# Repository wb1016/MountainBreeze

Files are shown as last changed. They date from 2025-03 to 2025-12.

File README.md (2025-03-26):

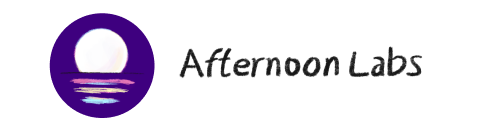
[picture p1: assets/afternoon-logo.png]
Afternoon Labs Logo


# Mountain Breeze

> Ergonomics meets Productivity.

## Introduction

"Mountain Breeze" is a tented split mechanical keyboard with a column-staggered layout. With a focus on productivity, Breeze features a full 6x4 alphanumeric layout, arrow keys, and an extra 6 key cluster for typing and coding.

Learn more at: [www.afternoonlabs.com/mountain-breeze](https://www.afternoonlabs.com/mountain-breeze)

## Features

* Tented Split Ergonomics
* Productivity Cluster for Typing and Coding
* Wireless-First, Fits a Giant Battery
* Built-in On/Off Switch
* Open-source PCB design for easy modifications
* Hotswap MX or Choc Sockets, MX Sockets Built-in!
* Diodes Built-in, No Diode Soldering Required
* Columnar Stagger
* Arrow Keys!

## Support us

Enjoying the Breeze? [Buy me a beer](https://www.buymeacoffee.com/Afternoonlabs).

## Contribution

Contributions are encouraged! Whether it's bug fixes, new features, or even simple feedback, everything helps in making the project better.

1. Fork the Project
2. Create your Feature Branch (`git checkout -b feature/SomeFeature`)
3. Commit your Changes (`git commit -m 'Adding SomeFeature'`)
4. Push to the Branch (`git push origin feature/SomeFeature`)
5. Open a Pull Request

## License

Anyone can use this project for personal use. Distributed under the MIT License. See `LICENSE` for more information.

Vendors interested in selling the Breeze, please contact us below.

The use of "Afternoon Labs" is protected under copyright law. Unauthorized use without express permission from "Afternoon Labs", is prohibited.

## Contact

Join our [Discord Server](https://discord.gg/9nsApe3GvG).

Afternoon Labs - [hi@afternoonlabs.com](mailto:hi@afternoonlabs.com)

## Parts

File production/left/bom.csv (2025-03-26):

Designator | Footprint | Quantity | Value | LCSC Part #
BATT_CONN1 | BATT_PADS | 1 | ~
D1, D10, D11, D12, D13, D14, D15, D16, D17, D18, D19, D2, D20, D21, D22, D23, D24, D3, D4, D5, D6, D7, D8, D9, DTC1, DTC2, DTC3, DTC4 | SOD-123FL | 28 | DIODE | C64898
H18, H19, H2, H3, H4, H5, H6, H7, H8, H9 | M3-HOLE | 10 | M3-HOLE
LGO1 | logo | 1 | Logo
MCU-MAIN1 | ProMicro_1-Sided | 1 | PRO-MICRO
PWR1 | SS12D00 | 1 | SW_SPDT | C145861
RST1 | SW_SPST_TL3342 | 1 | SW-RST | C2886897
STABL1 | Stabilizer_MX_2u | 1 | MX-STABILIZER-2U
SW1, SW10, SW11, SW12, SW13, SW14, SW15, SW16, SW17, SW18, SW19, SW2, SW20, SW21, SW22, SW23, SW24, SW3, SW4, SW5, SW6, SW7, SW8, SW9, TC1, TC2, TC3, TC4 | MX_Choc_Hotswap_1-Sided | 28 | CHOCXHSPCB-1U | C41430893

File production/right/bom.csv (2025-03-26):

Designator | Footprint | Quantity | Value | LCSC Part #
D1, D10, D11, D12, D13, D14, D15, D16, D17, D18, D19, D2, D20, D21, D22, D23, D24, D3, D4, D5, D6, D7, D8, D9, DALF1, DAN1, DMC1, DMC2, DMC3, DMC4, DMC5, DMC6, DRT1, DTC1, DTC2, DTC3, DTC4, DUP1 | SOD-123FL | 38 | DIODE | C64898
DOWN1, LEFT1, MC1, MC2, MC3, MC4, MC5, MC6, RIGHT1, SW1, SW10, SW11, SW12, SW13, SW14, SW15, SW16, SW17, SW18, SW19, SW2, SW20, SW21, SW22, SW23, SW24, SW3, SW4, SW5, SW6, SW7, SW8, SW9, TC1, TC2, TC3, TC4, UP1 | MX_Choc_Hotswap_1-Sided | 38 | CHOCXHSPCB-1U | C41430893
H1, H10, H16, H17, H18, H19, H2, H3, H4, H5, H6, H7, H8, H9 | M3-HOLE | 14 | M3-HOLE
H11, H13, H15 | M2-HOLE | 3 | 2M-HOLE
J1 | BATT_PADS | 1 | J
J_FUNCT1, J_RIGHT1 | PinHeader_1x03_P2.54mm_Vertical | 2 | Conn_01x04
J_FUNCT2, J_RIGHT2 | PinHeader_1x04_P2.54mm_Vertical | 2 | Conn_01x04
LGO1 | logo | 1 | Logo
MCU-MAIN1 | ProMicro_1-Sided | 1 | PRO-MICRO
PWR1 | SS12D00 | 1 | SW_SPDT | C145861
RST1 | SW_SPST_TL3342 | 1 | SW-RST | C2886897
STABL1 | Stabilizer_MX_2u | 1 | MX-STABILIZER-2U

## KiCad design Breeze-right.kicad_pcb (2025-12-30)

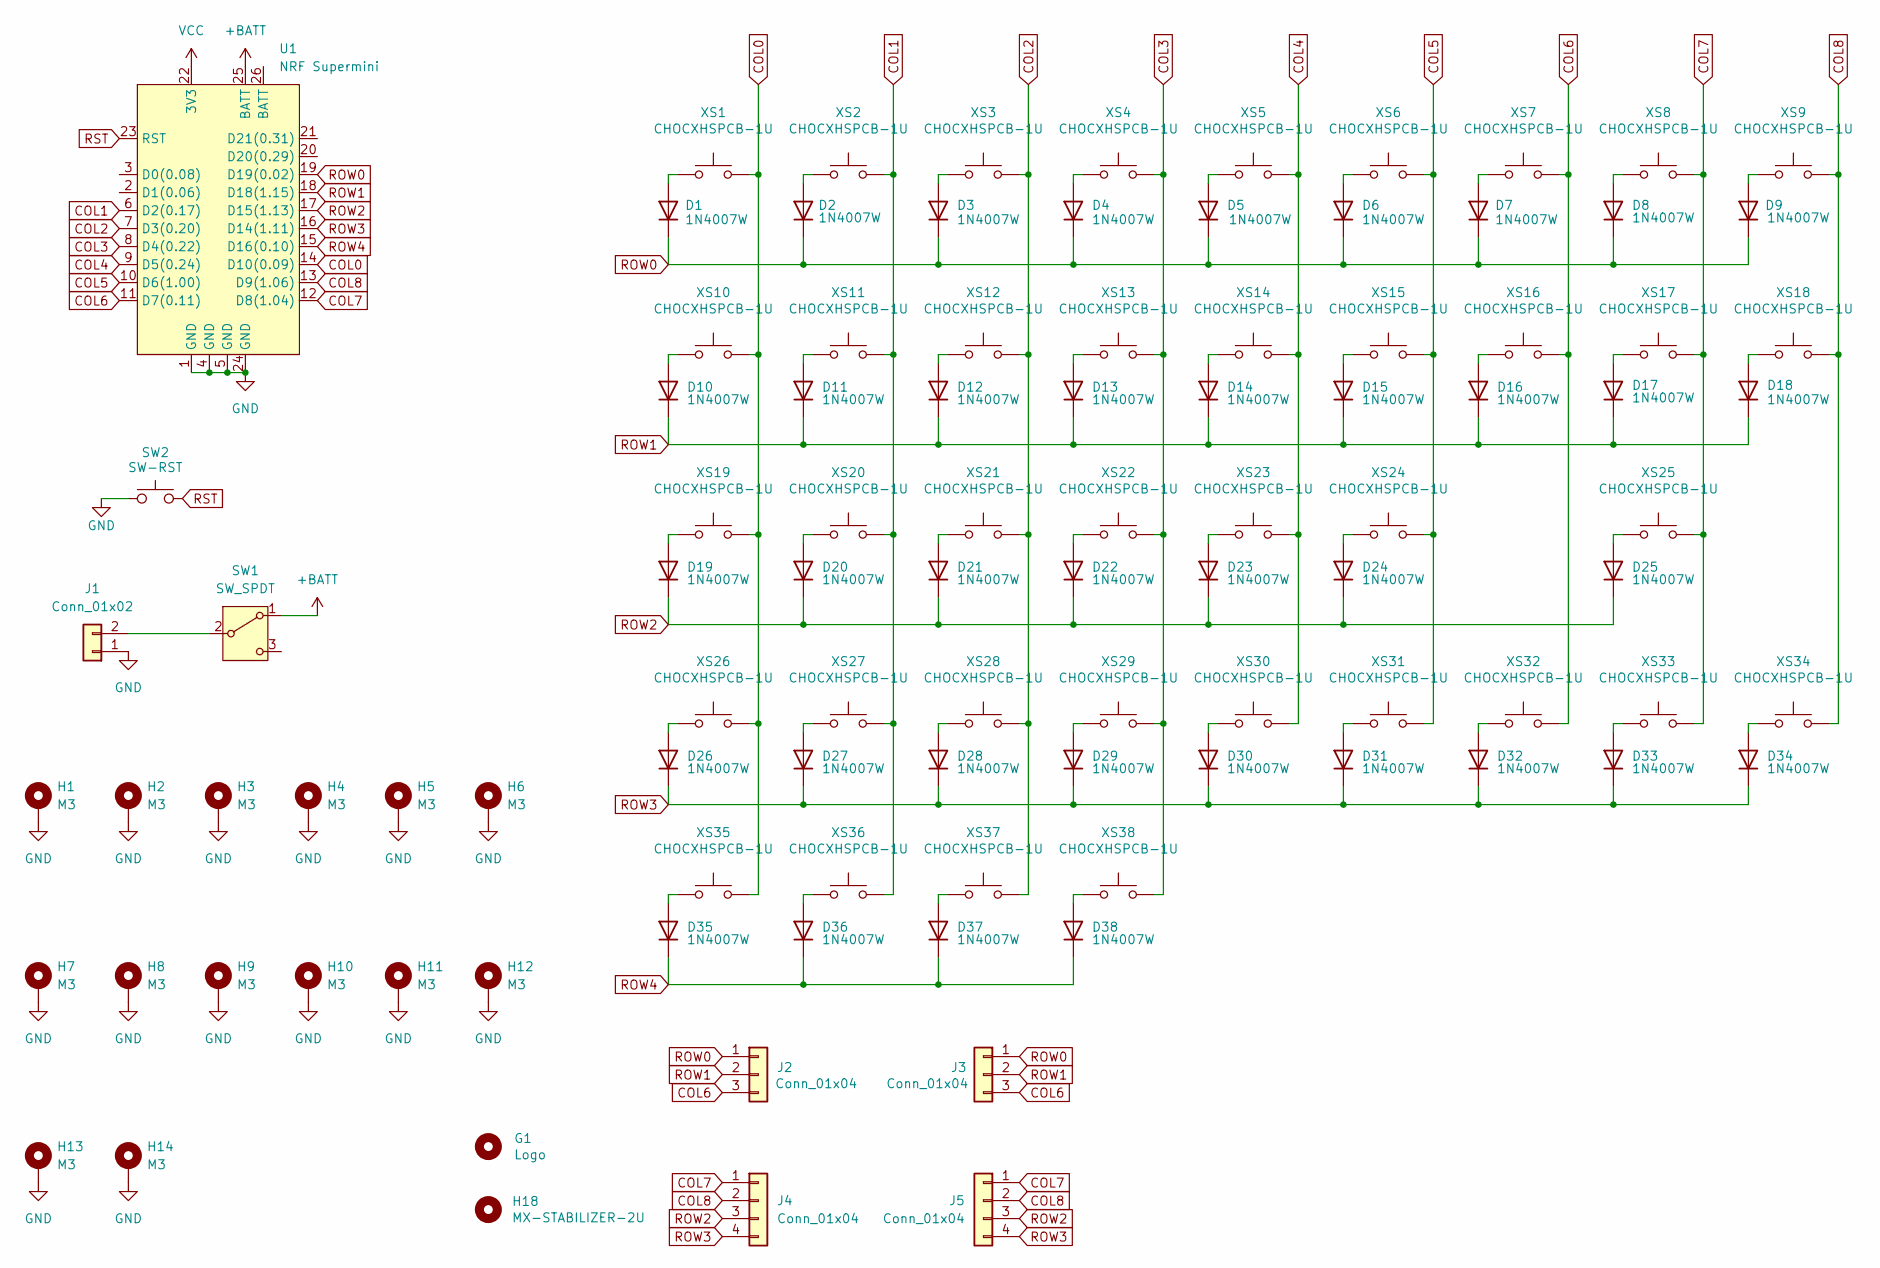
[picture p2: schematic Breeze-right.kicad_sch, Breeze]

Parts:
D1, D2, D3, D4, D5, D6, D7, D8, D9, D10, D11, D12, D13, D14, D15, D16, D17, D18, D19, D20, D21, D22, D23, D24, D25, D26, D27, D28, D29, D30, D31, D32, D33, D34, D35, D36, D37, D38: 1N4007W; SOD-123FL_L2.7-W1.8-LS3.7-RD; LCSC C64898
G1: Logo; logo
H1, H3, H4, H6, H7, H9, H10, H11, H12, H13, H14: M3; MountingHole_3.2mm_M3_ISO7380_Pad
H2, H5, H8: M3; MountingHole_3.2mm_M3_ISO7380_Pad_TopOnly
H18: MX-STABILIZER-2U; Stabilizer_MX_2u
J1: Conn_01x02; BATT_PADS
J2, J3: Conn_01x04; PinHeader_1x03_P2.54mm_Vertical
J4, J5: Conn_01x04; PinHeader_1x04_P2.54mm_Vertical
SW1: SW_SPDT; SS12D00; LCSC C145861
SW2: SW-RST; SW_SPST_TL3342; LCSC C2886897
U1: NRF Supermini; NRF_Supermini
XS1, XS2, XS3, XS4, XS5, XS6, XS7, XS8, XS9, XS10, XS11, XS12, XS13, XS14, XS15, XS16, XS17, XS18, XS19, XS20, XS21, XS22, XS23, XS24, XS25, XS26, XS27, XS28, XS29, XS30, XS31, XS32, XS33, XS34, XS35, XS36, XS37, XS38: CHOCXHSPCB-1U; MX_Choc_Hotswap_1-Sided; LCSC C41430893

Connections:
+BATT: SW1.1 (A), U1.25 (BATT)
COL0: U1.14 (D10(0.09)), XS1.2, XS10.2, XS19.2, XS26.2, XS35.2
COL1: U1.6 (D2(0.17)), XS2.2, XS11.2, XS20.2, XS27.2, XS36.2
COL2: U1.7 (D3(0.20)), XS3.2, XS12.2, XS21.2, XS28.2, XS37.2
COL3: U1.8 (D4(0.22)), XS4.2, XS13.2, XS22.2, XS29.2, XS38.2
COL4: U1.9 (D5(0.24)), XS5.2, XS14.2, XS23.2, XS30.2
COL5: U1.10 (D6(1.00)), XS6.2, XS15.2, XS24.2, XS31.2
COL6: J2.3, J3.3, U1.11 (D7(0.11)), XS7.2, XS16.2, XS32.2
COL7: J4.1, J5.1, U1.12 (D8(1.04)), XS8.2, XS17.2, XS25.2, XS33.2
COL8: J4.2, J5.2, U1.13 (D9(1.06)), XS9.2, XS18.2, XS34.2
GND: H1.1, H2.1, H3.1, H4.1, H5.1, H6.1, H7.1, H8.1, H9.1, H10.1, H11.1, H12.1, H13.1, H14.1, J1.1, SW2.1, U1.1 (GND), U1.4 (GND), U1.5 (GND), U1.24 (GND)
unnamed: D1.2 (A), XS1.1
unnamed: D2.2 (A), XS2.1
unnamed: D3.2 (A), XS3.1
unnamed: D4.2 (A), XS4.1
unnamed: D5.2 (A), XS5.1
unnamed: D6.2 (A), XS6.1
unnamed: D7.2 (A), XS7.1
unnamed: D8.2 (A), XS8.1
unnamed: D9.2 (A), XS9.1
unnamed: D10.2 (A), XS10.1
unnamed: D11.2 (A), XS11.1
unnamed: D12.2 (A), XS12.1
unnamed: D13.2 (A), XS13.1
unnamed: D14.2 (A), XS14.1
unnamed: D15.2 (A), XS15.1
unnamed: D16.2 (A), XS16.1
unnamed: D17.2 (A), XS17.1
unnamed: D18.2 (A), XS18.1
unnamed: D19.2 (A), XS19.1
unnamed: D20.2 (A), XS20.1
unnamed: D21.2 (A), XS21.1
unnamed: D22.2 (A), XS22.1
unnamed: D23.2 (A), XS23.1
unnamed: D24.2 (A), XS24.1
unnamed: D25.2 (A), XS25.1
unnamed: D26.2 (A), XS26.1
unnamed: D27.2 (A), XS27.1
unnamed: D28.2 (A), XS28.1
unnamed: D29.2 (A), XS29.1
unnamed: D30.2 (A), XS30.1
unnamed: D31.2 (A), XS31.1
unnamed: D32.2 (A), XS32.1
unnamed: D33.2 (A), XS33.1
unnamed: D34.2 (A), XS34.1
unnamed: D35.2 (A), XS35.1
unnamed: D36.2 (A), XS36.1
unnamed: D37.2 (A), XS37.1
unnamed: D38.2 (A), XS38.1
unnamed: J1.2, SW1.2 (B)
ROW0: D1.1 (K), D2.1 (K), D3.1 (K), D4.1 (K), D5.1 (K), D6.1 (K), D7.1 (K), D8.1 (K), D9.1 (K), J2.1, J3.1, U1.19 (D19(0.02))
ROW1: D10.1 (K), D11.1 (K), D12.1 (K), D13.1 (K), D14.1 (K), D15.1 (K), D16.1 (K), D17.1 (K), D18.1 (K), J2.2, J3.2, U1.18 (D18(1.15))
ROW2: D19.1 (K), D20.1 (K), D21.1 (K), D22.1 (K), D23.1 (K), D24.1 (K), D25.1 (K), J4.3, J5.3, U1.17 (D15(1.13))
ROW3: D26.1 (K), D27.1 (K), D28.1 (K), D29.1 (K), D30.1 (K), D31.1 (K), D32.1 (K), D33.1 (K), D34.1 (K), J4.4, J5.4, U1.16 (D14(1.11))
ROW4: D35.1 (K), D36.1 (K), D37.1 (K), D38.1 (K), U1.15 (D16(0.10))
RST: SW2.2, U1.23 (RST)
VCC: U1.22 (3V3)

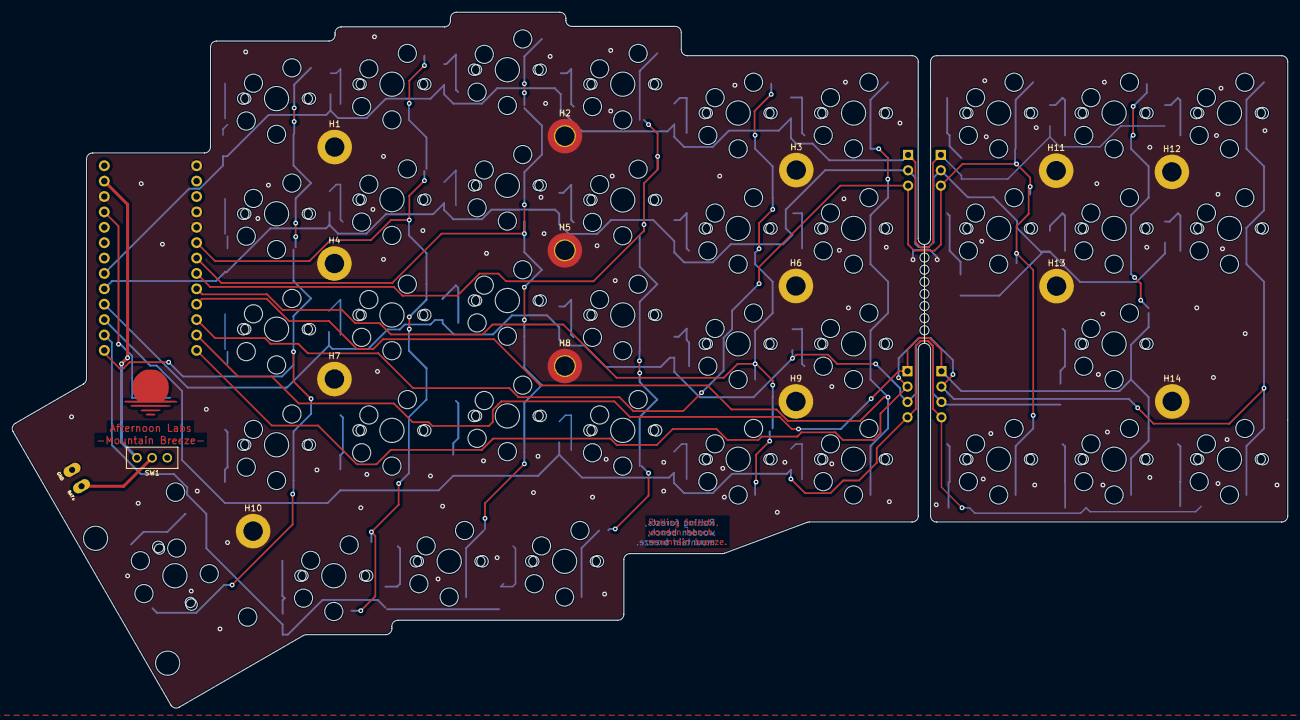
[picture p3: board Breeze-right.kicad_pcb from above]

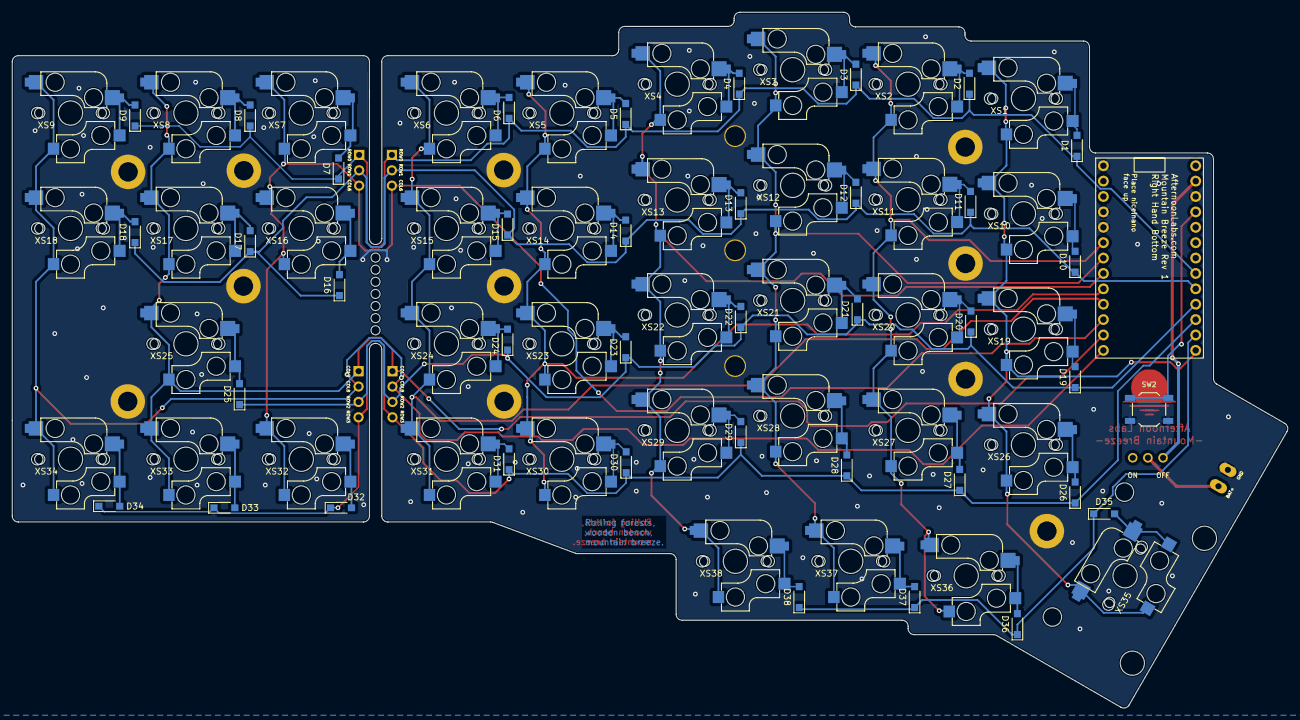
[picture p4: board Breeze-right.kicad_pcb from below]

Board: 2 copper layers, 210.6 x 114.9 mm, 100 parts (82 on the bottom side), 56 nets.

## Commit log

2025-03-26 Rev1.0 Release
    [Breeze-left.kicad_pcb, Breeze-left.kicad_sch, Breeze-right.kicad_pcb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]
2025-09-07 do left
    use gitignore
    [Breeze-left.kicad_pcb, Breeze-left.kicad_sch]
2025-12-01 redo left PCB, redraw supermini symbol
    [Breeze-left.kicad_pcb, Breeze-left.kicad_sch, Breeze-right.kicad_sch]
2025-12-15 trace width parity, correct arduino mounting side
    [Breeze-left.kicad_pcb, Breeze-right.kicad_pcb]
2025-12-30 fix mis-named component(xs25)
    [Breeze-left.kicad_pcb, Breeze-right.kicad_pcb, Breeze-right.kicad_sch]
